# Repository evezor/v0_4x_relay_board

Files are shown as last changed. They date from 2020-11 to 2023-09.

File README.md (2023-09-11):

# 4x Relay Board
*please note this board has been deprecated.

An edge board containing qty(4) 10 amp relays and qty(4) tactile buttons

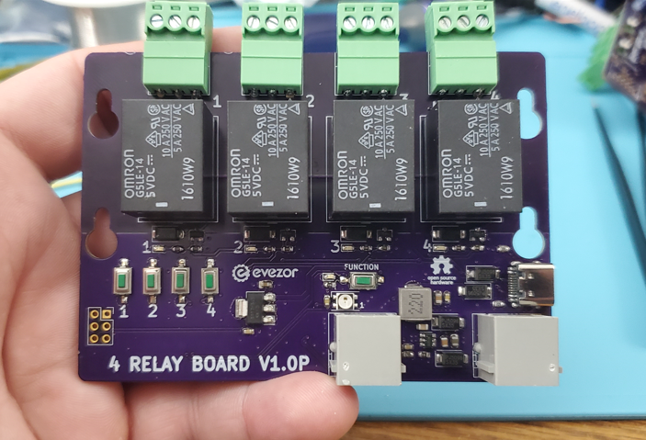
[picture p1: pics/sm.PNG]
sm


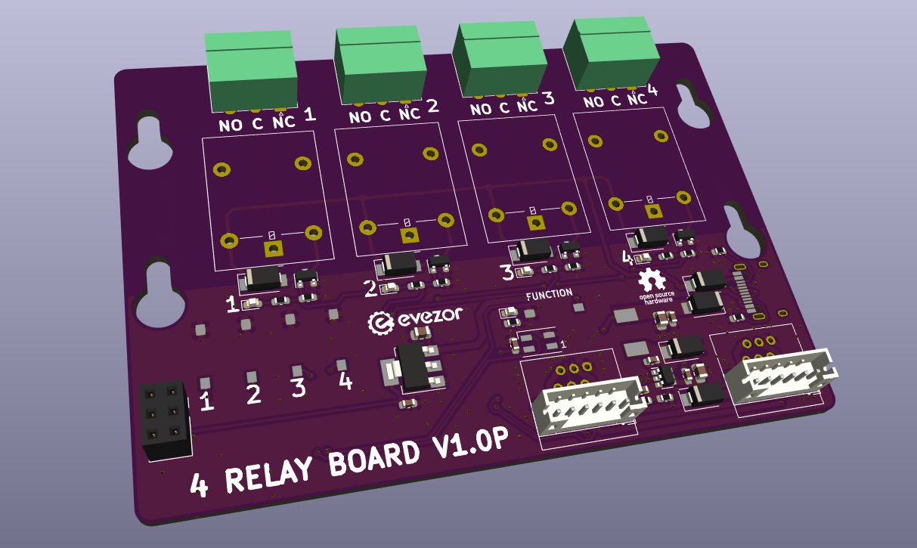
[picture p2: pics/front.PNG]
front


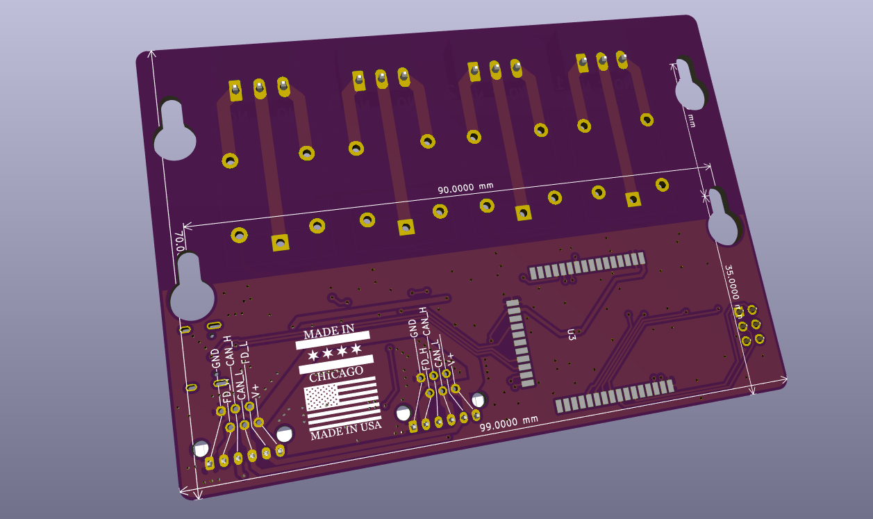
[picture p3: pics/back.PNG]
back


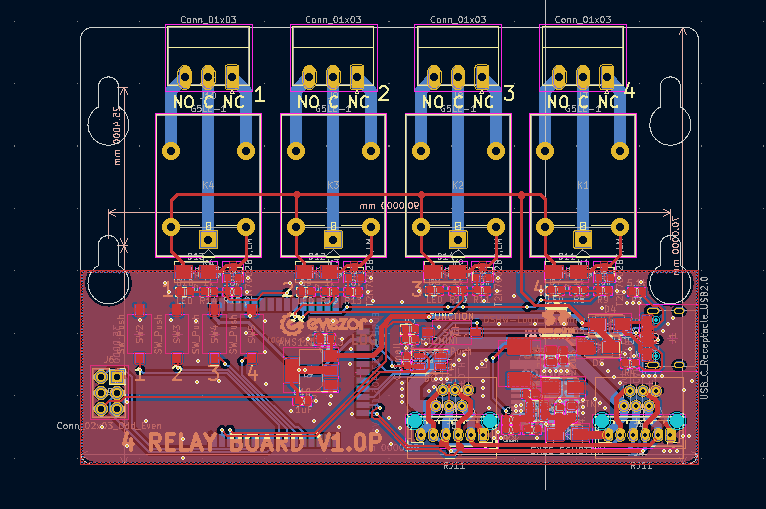
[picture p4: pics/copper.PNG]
copper


sch

source files can be found here: https://github.com/evezor/v0_4x_relay_board

This board uses the Evezor Stamp STMF405 MCU

source: https://github.com/evezor/Evezor-Stamp-STMF405

Evezor® and all associated marks, logos, and designs are registered trademarks and protected by copyright. Unauthorized use or reproduction of these trademarks and copyrighted materials is strictly prohibited.

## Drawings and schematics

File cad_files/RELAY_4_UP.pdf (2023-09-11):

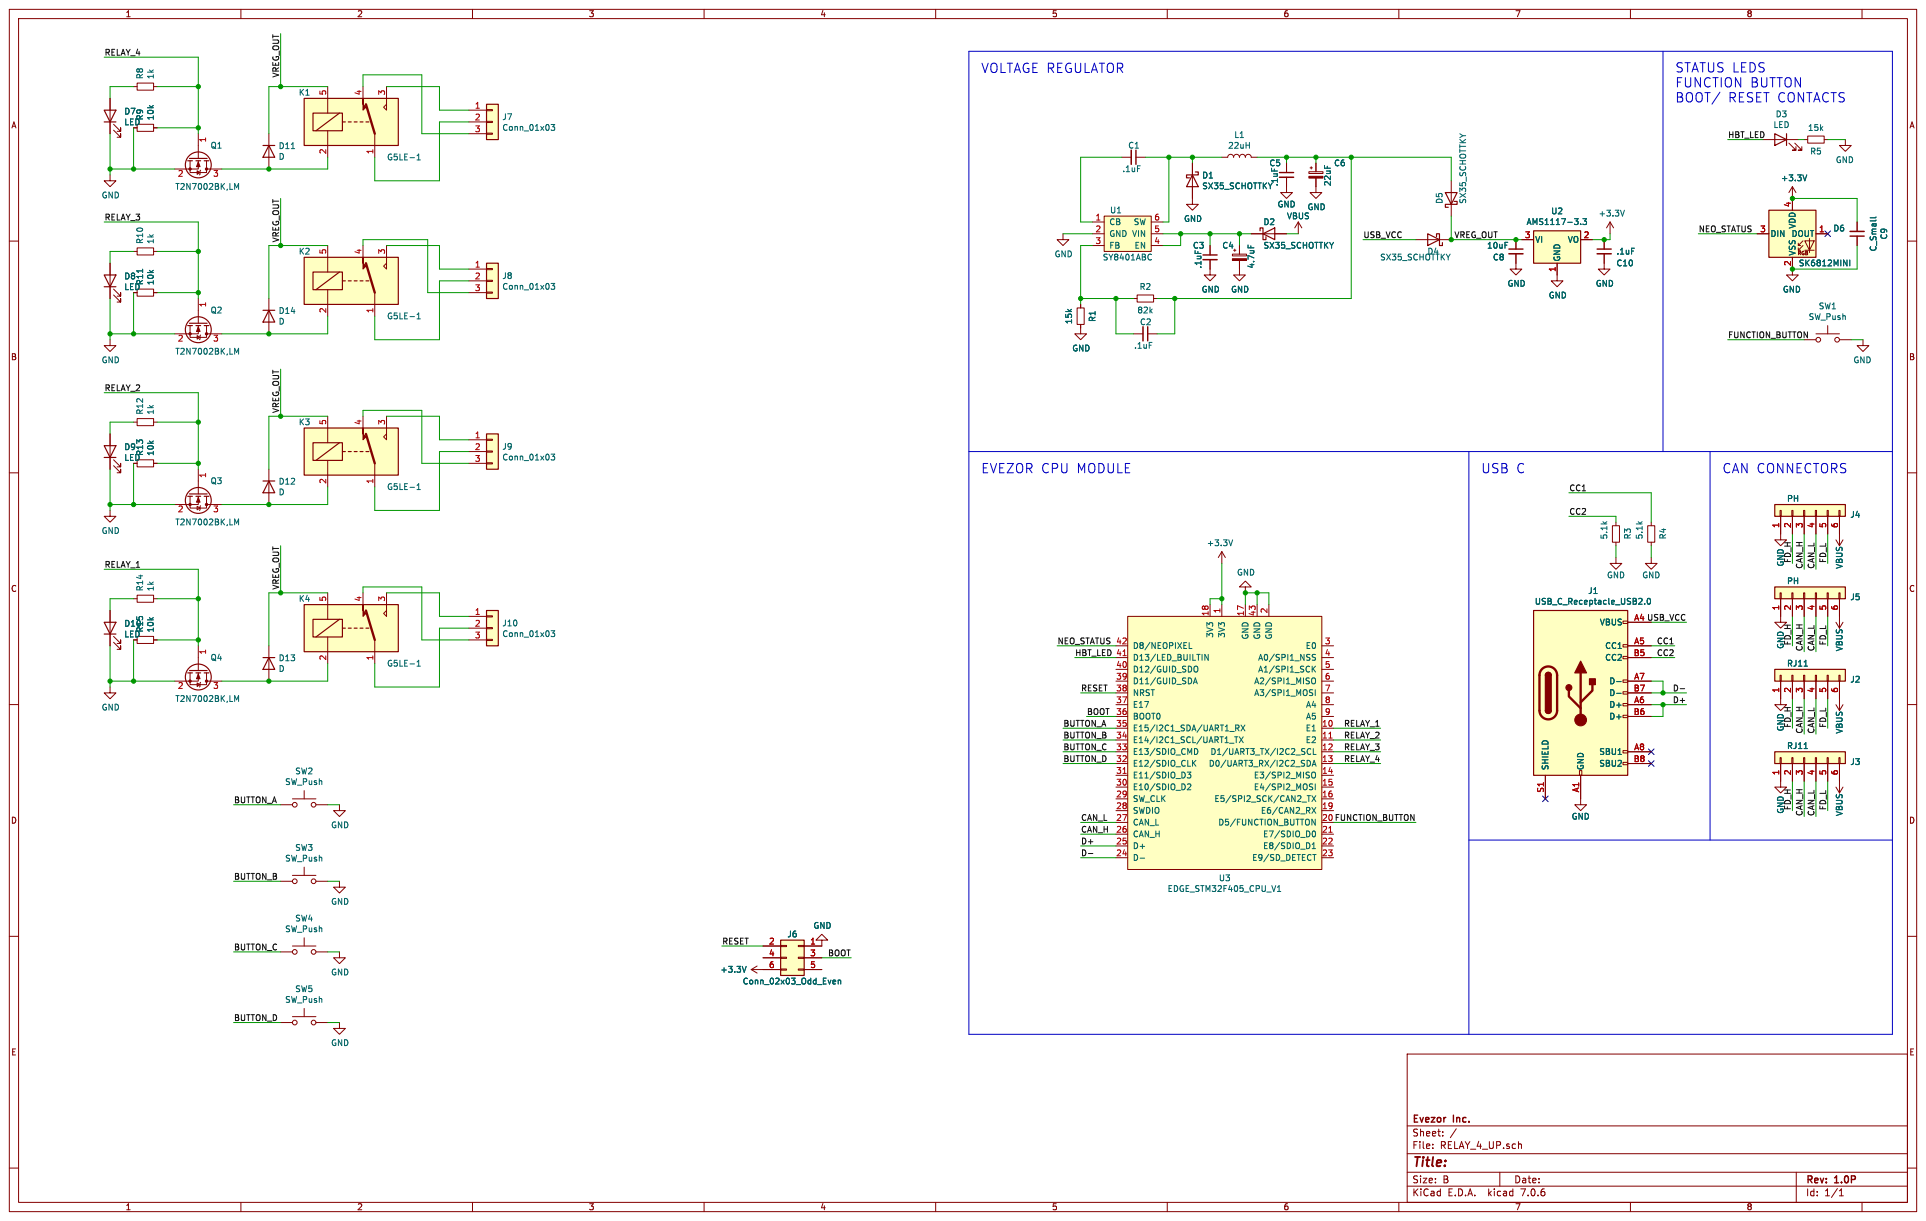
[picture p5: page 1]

USB C
J3 RJ11 123456 VBUS VBUS GND GND

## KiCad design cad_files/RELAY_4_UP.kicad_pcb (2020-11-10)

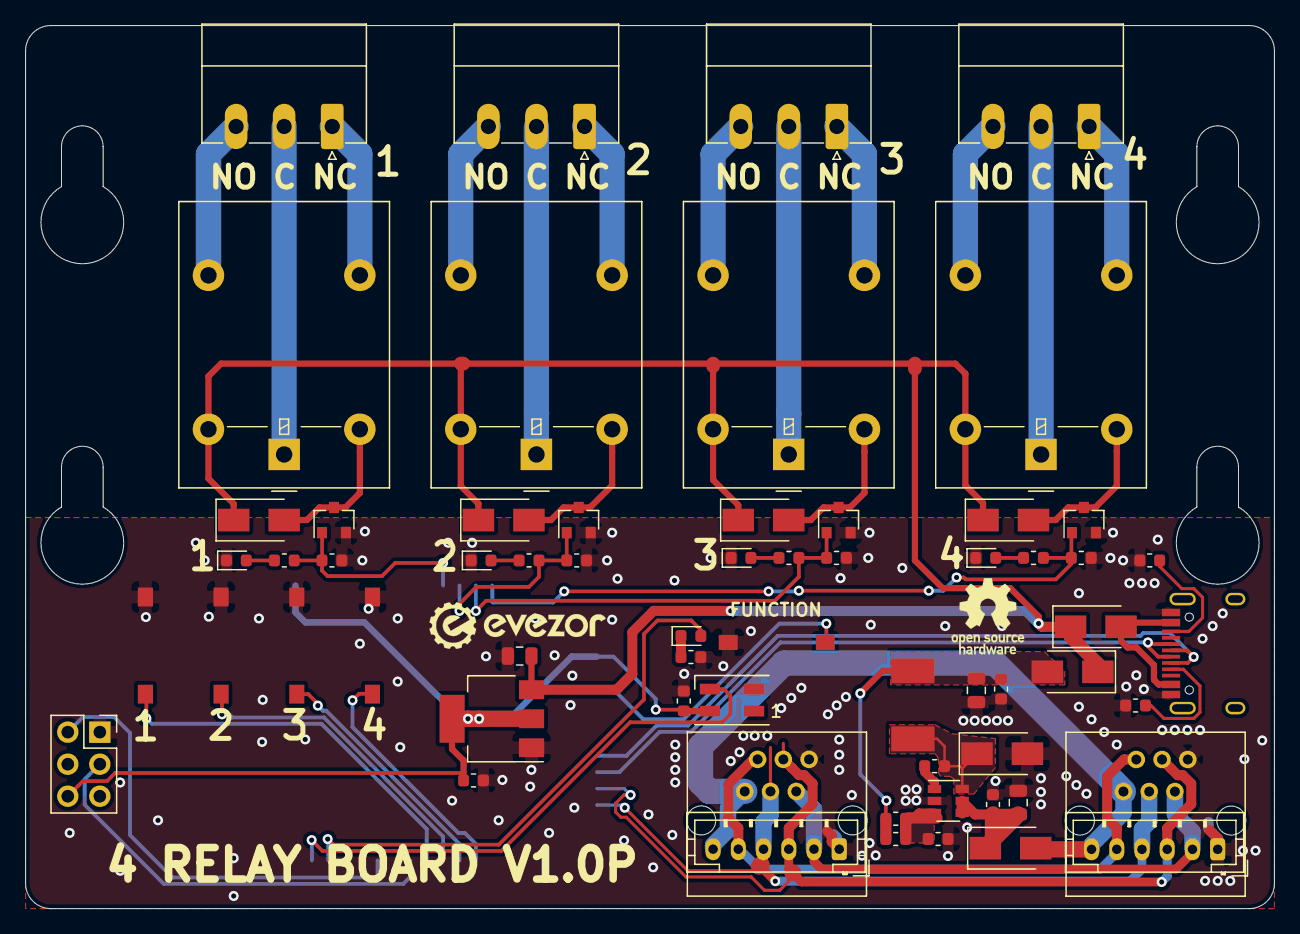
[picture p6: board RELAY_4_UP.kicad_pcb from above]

Board: 2 copper layers, 99.0 x 70.0 mm, 63 parts (1 on the bottom side), 52 nets.

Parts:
C1, C2, C3, C5, C10: .1uF; C_0603_1608Metric
C4: 4.7uF; C_0805_2012Metric
C6: 22uF; C_0805_2012Metric
C8: 10uF; C_0805_2012Metric
C9: C_Small; C_0603_1608Metric
D1, D2, D4, D5: SX35_SCHOTTKY; D_SMA
D3, D7, D8, D9, D10: LED; LED_0603_1608Metric
D6: SK6812MINI; LED_SK6812MINI_PLCC4_3.5x3.5mm_P1.75mm
D11, D12, D13, D14: D; D_SMA
J1: USB_C_Receptacle_USB2.0; USB_C_Receptacle_HRO_TYPE-C-31-M-12
J2, J3: RJ11; RJ11_C189747_Horizontal
J4, J5: PH; JST_PH_B6B-PH-K_1x06_P2.00mm_Vertical
J6: Conn_02x03_Odd_Even; PinSocket_2x03_P2.54mm_Vertical
J7, J8, J9, J10: Conn_01x03; PhoenixContact_MC_1,5_3-G-3.81_1x03_P3.81mm_Horizontal
K1, K2, K3, K4: G5LE-1; Relay_SPDT_Omron-G5LE-1
L1: 22uH; INDUCTOR_7.5X6.6_GCDA0630-220MC
Q1, Q2, Q3, Q4: T2N7002BK,LM‎; SOT-23
R1, R5: 15k; R_0603_1608Metric
R2: 82k; R_0603_1608Metric
R3, R4: 5.1k; R_0603_1608Metric
R8, R10, R12, R14: 1k; R_0603_1608Metric
R9, R11, R13, R15: 10k; R_0603_1608Metric
SW1, SW2, SW3, SW4, SW5: SW_Push; SWITCH_2x3_SMD_TACTILE_GREEN
U1: SY8401ABC; SOT-23-6
U2: AMS1117-3.3; SOT-223-3_TabPin2
U3: EDGE_STM32F405_CPU_V1; EDGE_STAMP

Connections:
+3V3: C9.2, C10.1, D6.4, J6.6, U2.2, U3.1, U3.18
/BOOT: J6.3, U3.36
/BUTTON_A: SW2.1, U3.35
/BUTTON_B: SW3.1, U3.34
/BUTTON_C: SW4.1, U3.33
/BUTTON_D: SW5.1, U3.32
/CAN_H: J2.3, J3.3, J4.3, J5.3, U3.26
/CAN_L: J2.4, J3.4, J4.4, J5.4, U3.27
/CC1: J1.A5, R4.1
/CC2: J1.B5, R3.1
/D+: J1.A6, J1.B6, U3.25
/D-: J1.A7, J1.B7, U3.24
/FD_H: J2.2, J3.2, J4.2, J5.2
/FD_L: J2.5, J3.5, J4.5, J5.5
/FUNCTION_BUTTON: SW1.1, U3.20
/HBT_LED: D3.2, U3.41
/NEO_STATUS: D6.3, U3.42
/RELAY_1: Q4.1, R14.1, R15.2, U3.10
/RELAY_2: Q3.1, R12.1, R13.2, U3.11
/RELAY_3: Q2.1, R10.1, R11.2, U3.12
/RELAY_4: Q1.1, R8.1, R9.2, U3.13
/RESET: J6.2, U3.38
/USB_VCC: D4.2, J1.A4, J1.A9, J1.B4, J1.B9
/VREG_OUT: C8.1, D4.1, D5.1, D11.1, D12.1, D13.1, D14.1, K1.5, K2.5, K3.5, K4.5, U2.3
GND: C3.2, C4.2, C5.2, C6.2, C8.2, C9.1, C10.2, D1.2, D6.2, D7.1, D8.1, D9.1, D10.1, J1.A1, J1.A12, J1.B1, J1.B12, J2.1, J3.1, J4.1, J5.1, J6.1, Q1.2, Q2.2, Q3.2, Q4.2, R1.1, R3.2, R4.2, R5.1, R9.1, R11.1, R13.1, R15.1, SW1.2, SW2.2, SW3.2, SW4.2, SW5.2, U1.2, U2.1, U3.2, U3.17, U3.43
unnamed: C1.1, D1.1, L1.1, U1.6
unnamed: C1.2, U1.1
unnamed: C2.1, C5.1, C6.1, D5.2, L1.2, R2.1
unnamed: C2.2, R1.2, R2.2, U1.3
unnamed: C3.1, C4.1, D2.1, U1.4, U1.5
unnamed: D3.1, R5.2
unnamed: D7.2, R8.2
unnamed: D8.2, R10.2
unnamed: D9.2, R12.2
unnamed: D10.2, R14.2
unnamed: D11.2, K1.2, Q1.3
unnamed: D12.2, K3.2, Q3.3
unnamed: D13.2, K4.2, Q4.3
unnamed: D14.2, K2.2, Q2.3
unnamed: J7.1, K1.3
unnamed: J7.2, K1.1
unnamed: J7.3, K1.4
unnamed: J8.1, K2.3
unnamed: J8.2, K2.1
unnamed: J8.3, K2.4
unnamed: J9.1, K3.3
unnamed: J9.2, K3.1
unnamed: J9.3, K3.4
unnamed: J10.1, K4.3
unnamed: J10.2, K4.1
unnamed: J10.3, K4.4
VBUS: D2.2, J2.6, J3.6, J4.6, J5.6

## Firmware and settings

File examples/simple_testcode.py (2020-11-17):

#4x relay board v1.0p test code

from machine import Pin
from pyb import CAN
import utime


print("starting relay board test")
print("v1.0")
print("initializing")
can = CAN(1, CAN.NORMAL)
can.setfilter(0, CAN.LIST16, 0, (123, 124, 125, 126))


#Setup Pins
hbt_led = Pin("D13", Pin.OUT)
func_butt = Pin("D5", Pin.IN, Pin.PULL_UP) 
can_wakeup = Pin("D6", Pin.OUT)
can_wakeup.value(0)


RELAY_1 = Pin("E1", Pin.OUT)
RELAY_2 = Pin("E2", Pin.OUT)
RELAY_3 = Pin("D1", Pin.OUT)
RELAY_4 = Pin("D0", Pin.OUT)

BUTTON_A = Pin("E15", Pin.IN, Pin.PULL_UP) 
BUTTON_B = Pin("E14", Pin.IN, Pin.PULL_UP) 
BUTTON_C = Pin("E13", Pin.IN, Pin.PULL_UP) 
BUTTON_D = Pin("E12", Pin.IN, Pin.PULL_UP) 

    
    
#Setup hbt timer
hbt_state = 0
hbt_interval = 500
start = utime.ticks_ms()
next_hbt = utime.ticks_add(start, hbt_interval)
hbt_led.value(hbt_state)


print("starting")


def chk_hbt():
    global next_hbt
    global hbt_state
    now = utime.ticks_ms()
    if utime.ticks_diff(next_hbt, now) <= 0:
        if hbt_state == 1:
            hbt_state = 0
            hbt_led.value(hbt_state)
            #print("hbt")
        else:
            hbt_state = 1
            hbt_led.value(hbt_state)  
        
        next_hbt = utime.ticks_add(next_hbt, hbt_interval)

      

def send():
    can.send('EVZRTEST', 123)   # send a message with id 123
    
def get():
    mess = can.recv(0)
    print(mess)
    relay_chase()

        
def relay_chase():
    RELAY_1.value(1)
    utime.sleep_ms(300) 
    RELAY_1.value(0)
    RELAY_2.value(1)
    utime.sleep_ms(300) 
    RELAY_2.value(0)
    RELAY_3.value(1)
    utime.sleep_ms(300) 
    RELAY_3.value(0)
    RELAY_4.value(1)
    utime.sleep_ms(300) 
    RELAY_4.value(0)
    RELAY_1.value(1)
    utime.sleep_ms(300) 
    RELAY_1.value(0)
    RELAY_2.value(1)
    utime.sleep_ms(300) 
    RELAY_2.value(0)
    RELAY_3.value(1)
    utime.sleep_ms(300) 
    RELAY_3.value(0)
    RELAY_4.value(1)
    utime.sleep_ms(300) 
    RELAY_4.value(0)
      
while True:
    chk_hbt()
    if not (func_butt.value()):
        print("function button")
        send()
        relay_chase()
        utime.sleep_ms(200)
    
    if(can.any(0)):
        get()
    
    if not (BUTTON_A.value()):
        print("BUTTON A pressed")
        RELAY_1.value(1)
        utime.sleep_ms(500) 
        RELAY_1.value(0)
    if not (BUTTON_B.value()):
        print("BUTTON B pressed")
        RELAY_2.value(1)
        utime.sleep_ms(500) 
        RELAY_2.value(0)
    if not (BUTTON_C.value()):
        print("BUTTON C pressed")
        RELAY_3.value(1)
        utime.sleep_ms(500) 
        RELAY_3.value(0)
    if not (BUTTON_D.value()):
        print("BUTTON D pressed")
        RELAY_4.value(1)
        utime.sleep_ms(500) 
        RELAY_4.value(0)
        
        
        
        
